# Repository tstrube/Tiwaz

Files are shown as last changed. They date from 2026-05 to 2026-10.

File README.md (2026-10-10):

# Tiwaz

Tiwaz is a split keyboard with gasket mounted plate and hot-swappable switches. Each half works standalone as a one-handed controller or macro pad. This makes this one of the only gaming keyboards for left handed users. 

The defining feature are the joysticks. They can operate as regular analog gamepad sticks, digital buttons, or mouse input, and use ribbon cables to connect to the PCB.

There are multiple options including solder pads that allow access to the joysticks pins for custom applications.

QMK and VIAL support allow button remapping in the browser without manual reflashing.

### TLDR Links:

- Detailed project presentation: [Hackaday](https://hackaday.io/project/206615-tiwaz-gaming-keyboard-macro-pad/details)
- Purchase here: [Crowd Supply](https://www.crowdsupply.com/ts-consulting/tiwaz)
- CAD files: [Printables](https://www.printables.com/model/1715647-tiwaz-split-gaming-keyboard-gasket-mounted), [Makerworld](https://makerworld.com/en/models/3280355-tiwaz-gaming-keyboard-macropad), [Thingiverse](https://www.thingiverse.com/thing:7404971)
- Custom keycaps: [Left half](https://custom.fkcaps.com/custom/ZMRFDB), [Right half](https://custom.fkcaps.com/custom/MJQDKY), [Both](https://custom.fkcaps.com/custom/L3QJ2N)
- Assembly video: [YouTube](https://www.youtube.com/watch?v=tHYdIYXT8AQ)
- Firmware: [QMK](https://github.com/tstrube/qmk_firmware/tree/tiwaz/keyboards/tiwaz), [VIAL](https://github.com/tstrube/vial-qmk/tree/tiwaz/keyboards/tiwaz)
- Subreddit: [Reddit](https://www.reddit.com/r/TiwazKeyboard/)
- Get in touch: [X](https://x.com/TimoStrube)

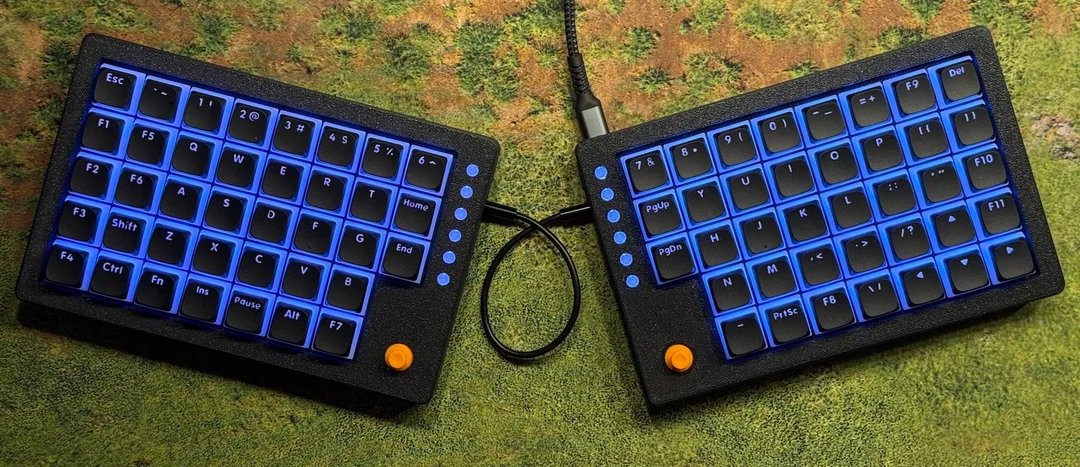
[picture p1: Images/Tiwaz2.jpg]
Tiwaz Split

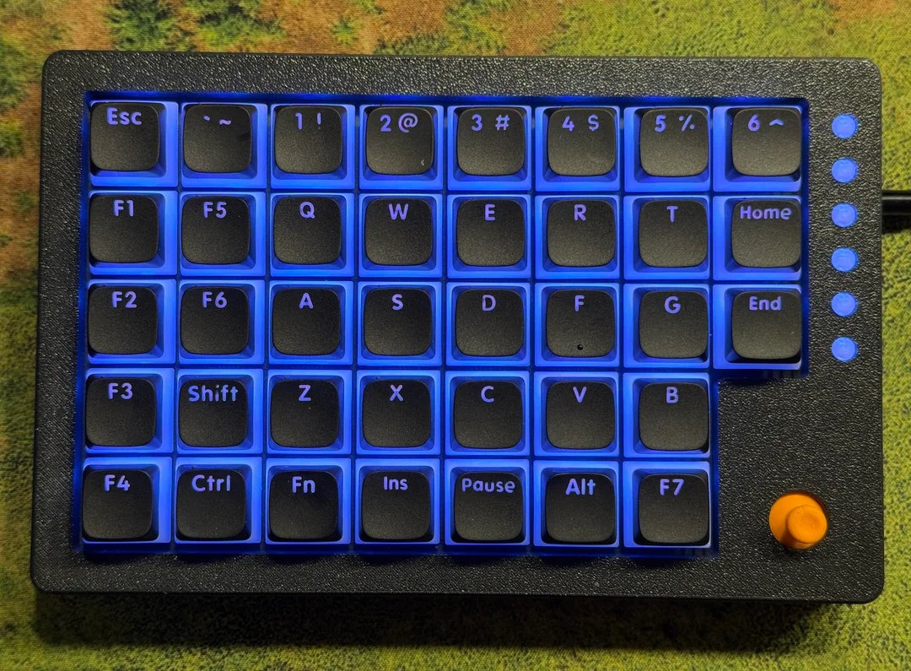
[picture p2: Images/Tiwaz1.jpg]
Detail

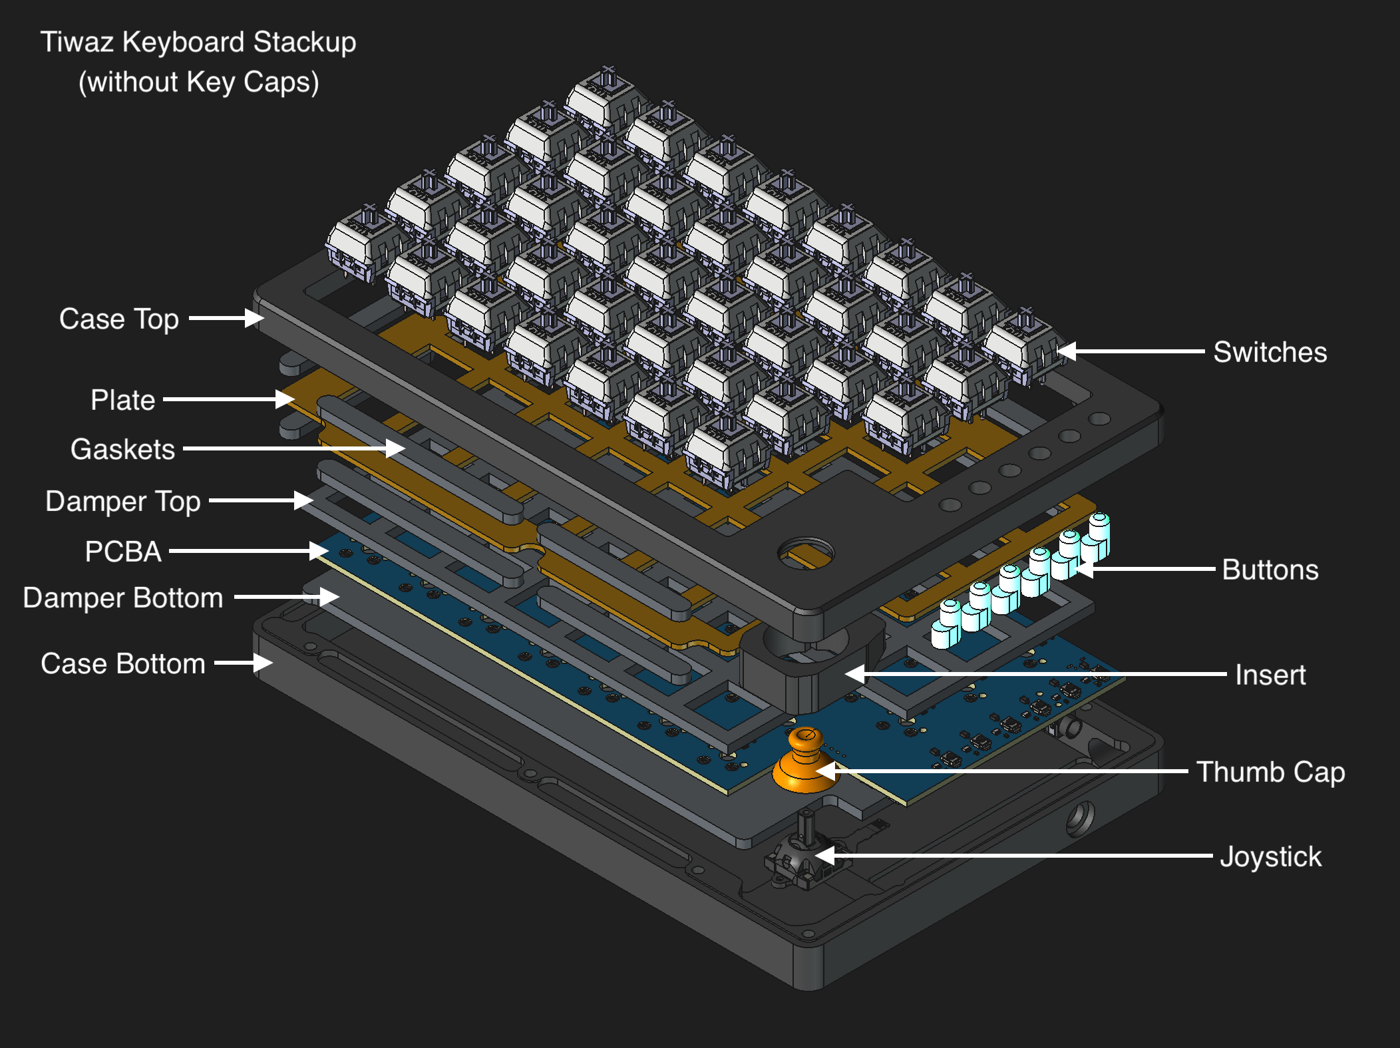
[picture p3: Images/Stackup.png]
Exploded view

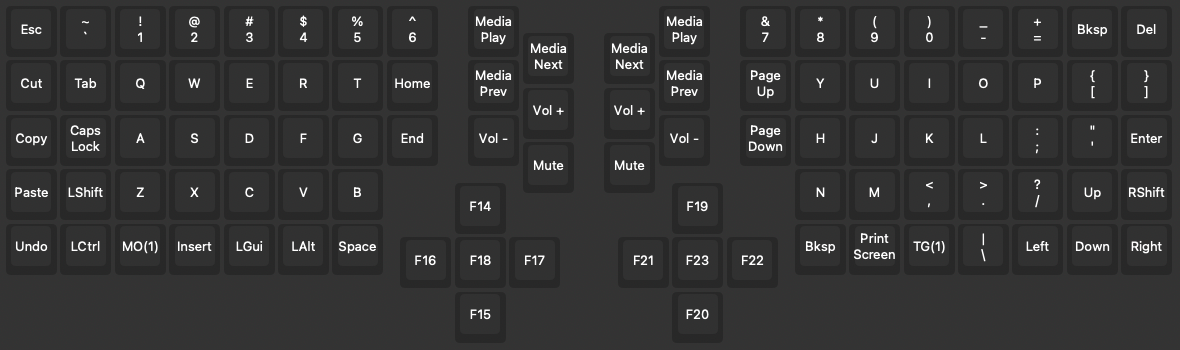
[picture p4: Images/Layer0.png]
Layer 0

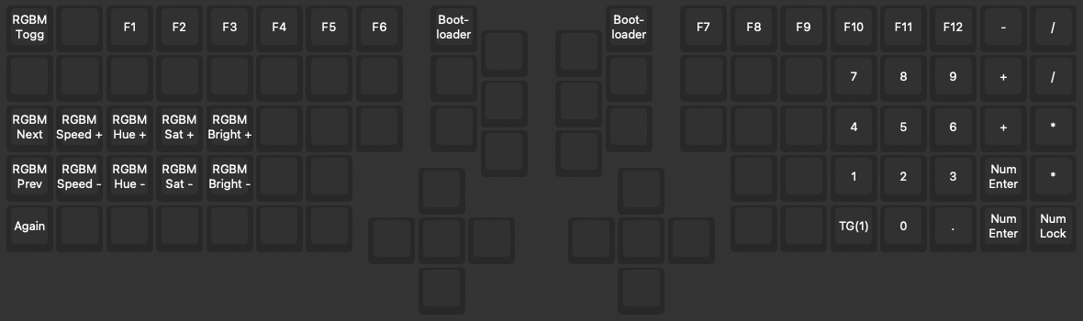
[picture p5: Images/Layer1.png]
Layer 1


[More Images](Images/README.md)

## Features

- Each half usable standalone as a one-handed controller or macro pad
- Two joystick options (Alps Alpine [RKJX21224001](https://tech.alpsalpine.com/e/products/detail/RKJX21224001/) / [PSP3000-style RKJXU1210006](https://tech.alpsalpine.com/e/products/detail/RKJXU1210006/))
- 6 separate media keys
- all switches and buttons are RGB backlit
- FN + lowest media key switch Joystick input mode (digital buttons (blue indicator light), analog gamepad (yellow), mouse (red))
  - digital buttons: 4 directions + center button, can be used as regular buttons or arrow keys, for example
  - analog gamepad: the joysticks are recognized as gamepad axes with a gamepad button
  - mouse: the joysticks control the mouse cursor, clicking by pressing the joystick down. To drag move before 500ms after pressing down, otherwise it will be a right click.
  - the indicator light is hardcoded. It is recommended to not change this key mapping
- Gasket mounted plate for a dampened typing feel
- Dapening material between Plate and PCB, as well as PCB and case
- [QMK firmware](https://github.com/tstrube/qmk_firmware/tree/tiwaz/keyboards/tiwaz) *([pull-request pending](https://github.com/qmk/qmk_firmware/pull/26438))* - [QMK website](https://www.qmk.fm/)
- [VIAL firmware](https://github.com/tstrube/vial-qmk/tree/tiwaz/keyboards/tiwaz) *(pull-request after QMK merged)* - [VIAL website](https://get.vial.today/)

## PCB details

- STM32F401RET6 MCU
- 38 hot-swap connectors for MX type switches
- 6 auxiliary buttons (intended as media keys, but remappable, of course)
- WS2812 RGB LED for each switch and button
- AUX connector for power and data transmission to the other half (only one half should be connected to the PC at any time)
- Ideal diode to protect against accidentally plugging in both halves while they are connect to each other
- Self-resetting fuse to to protect against high power draw of the LEDs (though limited in firmware)
- ESD protection on the USB and AUX connectors
- Solder points for joystick pins (ADC (2x), GPIO, GND, 3V3) 

## Bill of Materials

- PCB available on [Crowd Supply](https://www.crowdsupply.com/ts-consulting/tiwaz)
- Case available on [Printables](https://www.printables.com/model/1715647-tiwaz-split-gaming-keyboard-gasket-mounted), [Makerworld](https://makerworld.com/en/models/3280355-tiwaz-gaming-keyboard-macropad), [Thingiverse](https://www.thingiverse.com/thing:7404971)
- Ergo Keycaps (not affiliated, just recommendations. There are very few backlit 1u sets available)
  - FK custom: [Left half](https://custom.fkcaps.com/custom/ZMRFDB), [Right half](https://custom.fkcaps.com/custom/MJQDKY), [Both halves](https://custom.fkcaps.com/custom/L3QJ2N)
  - [LPF Glow Legended Low Profile MX Keycaps](https://splitkb.com/products/lpf-glow-legended-mx-keycaps)
  - [THT (Tai-Hao Thins) Low Profile Keycaps - 98 PCS](https://shop.tai-hao.com/products/98black)
  - [THT (Tai-Hao Thins) Low Profile Keycaps - 65 Keys](https://shop.tai-hao.com/products/black-low-profile-keycaps)
  - [THT (Tai-Hao Thins) Low Profile Keycaps - Blanks](https://shop.tai-hao.com/products/taihao-black-low-profile-keycap-1u-dot-pbt-backlit)

## Assembly video

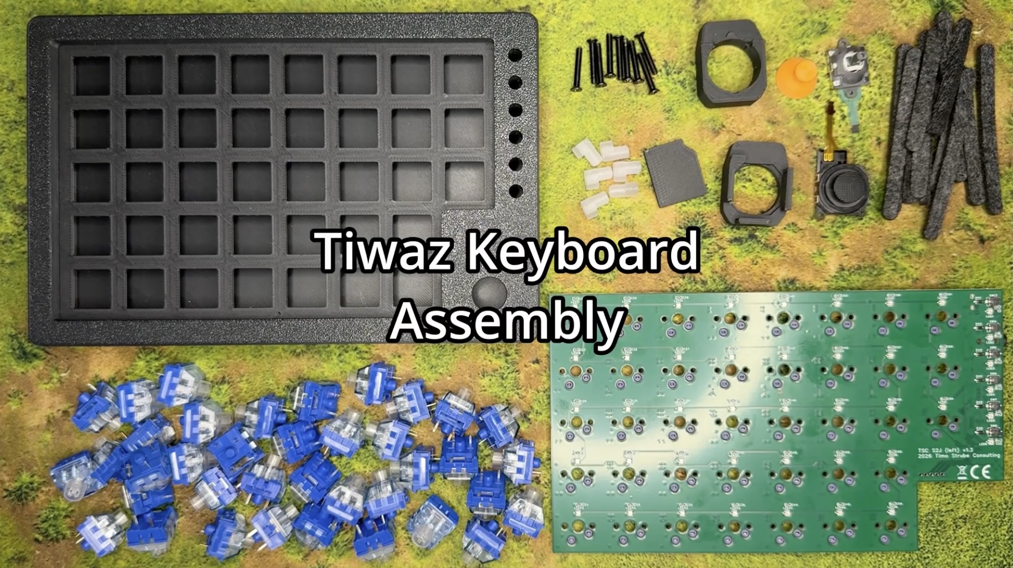
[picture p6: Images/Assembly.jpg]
Tiwaz Assembly (https://www.youtube.com/watch?v=tHYdIYXT8AQ)

[Watch the assembly video on YouTube](https://www.youtube.com/watch?v=tHYdIYXT8AQ)

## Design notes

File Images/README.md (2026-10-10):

Tiwaz Split
*Split keyboard*

---

Tiwaz Detail
*Left half detail view*

---

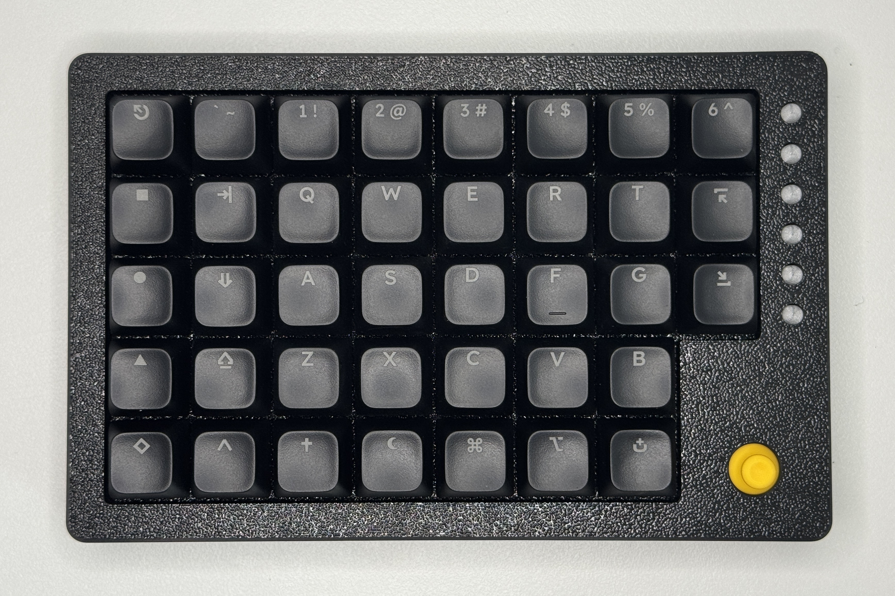
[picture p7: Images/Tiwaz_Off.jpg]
Tiwaz Off

*Backlight off*

---

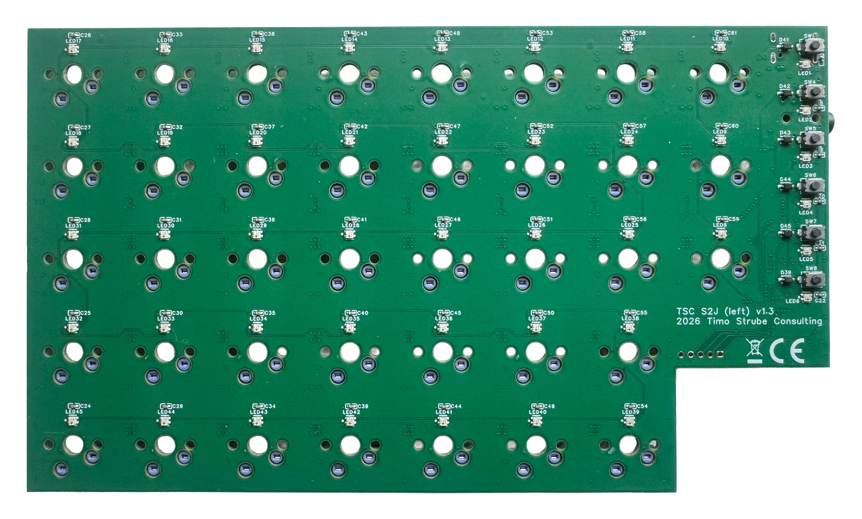
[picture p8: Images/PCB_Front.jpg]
Tiwaz PCB

*PCB front*

---

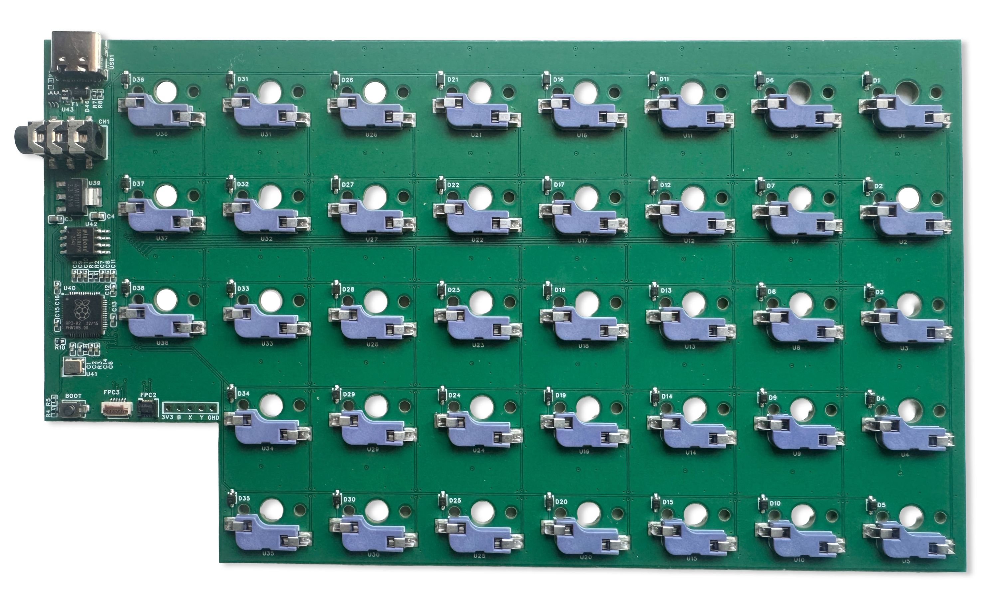
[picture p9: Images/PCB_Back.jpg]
Tiwaz PCB Back

*PCB back (old version with RP2040 instead of STM32F401)*

---

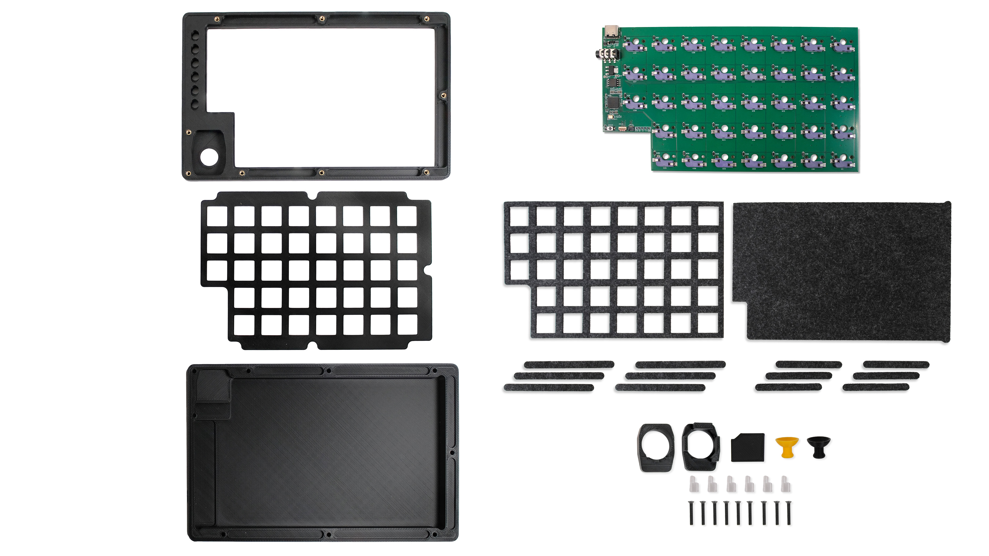
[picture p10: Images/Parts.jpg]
Tiwaz Parts

*All parts of one half of the keyboard*

---

Tiwaz Stackup
*Keyboard stackup*

---

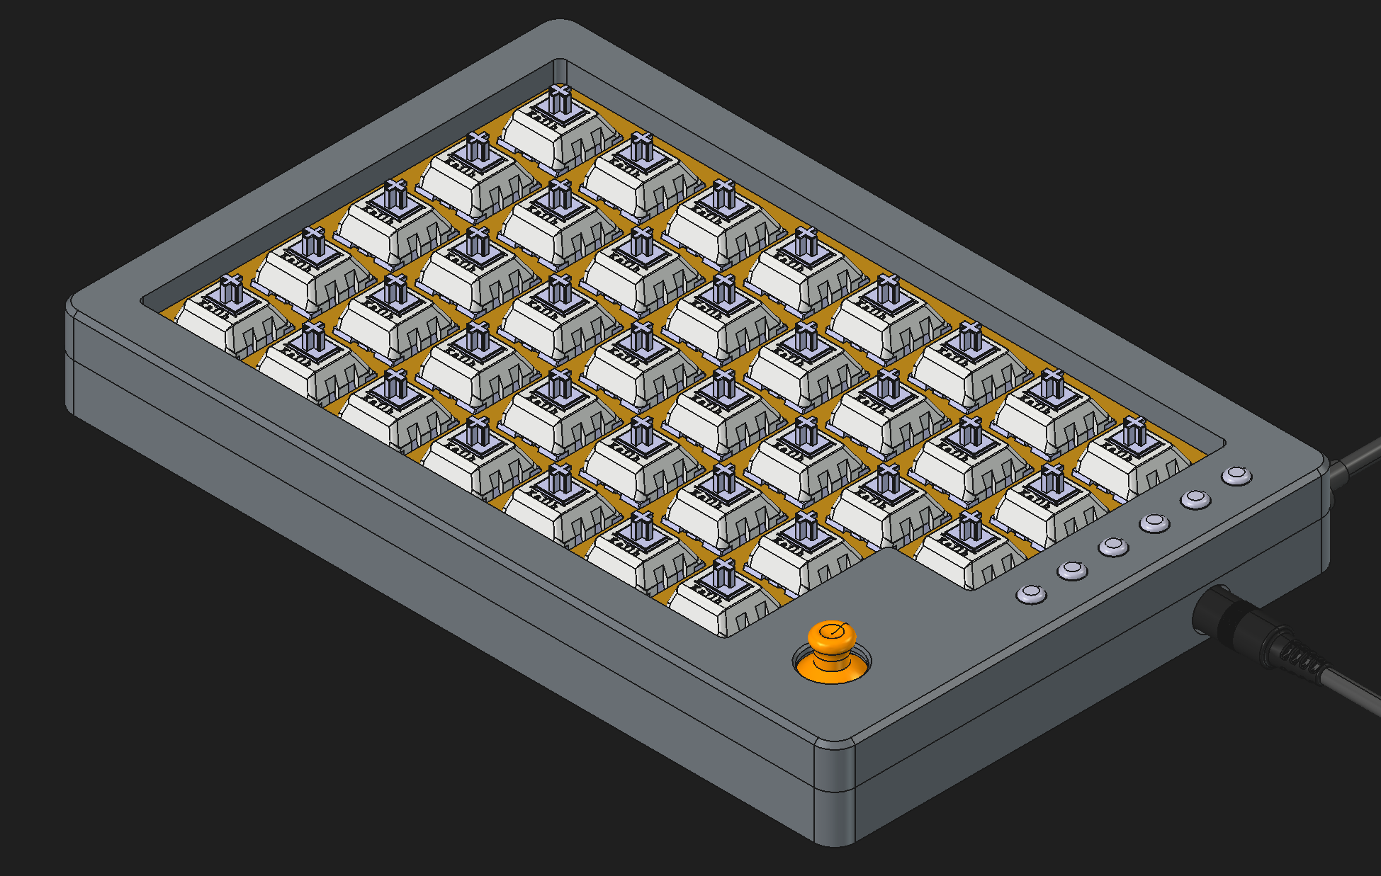
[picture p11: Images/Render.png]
Tiwaz Render

*3D Render*

---

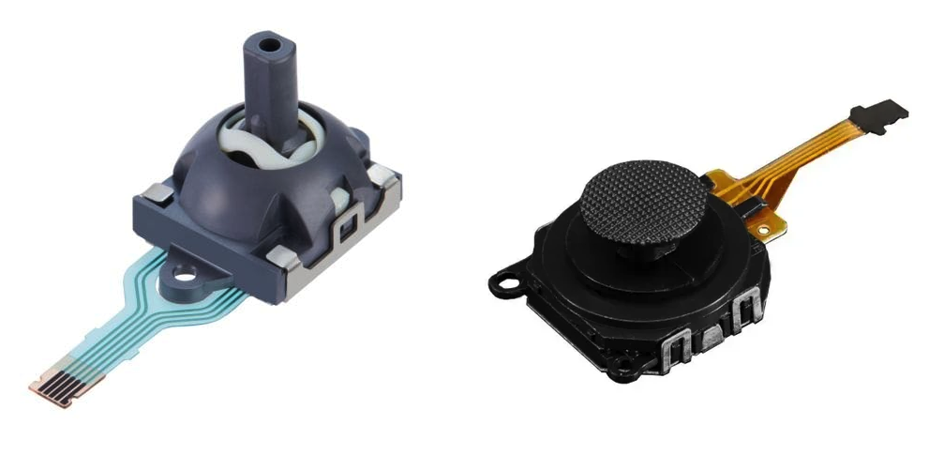
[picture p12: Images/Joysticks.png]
Joystick options

*Joystick options (left: RKJX21224001, right: RKJXU1210006 (PSP3000))*

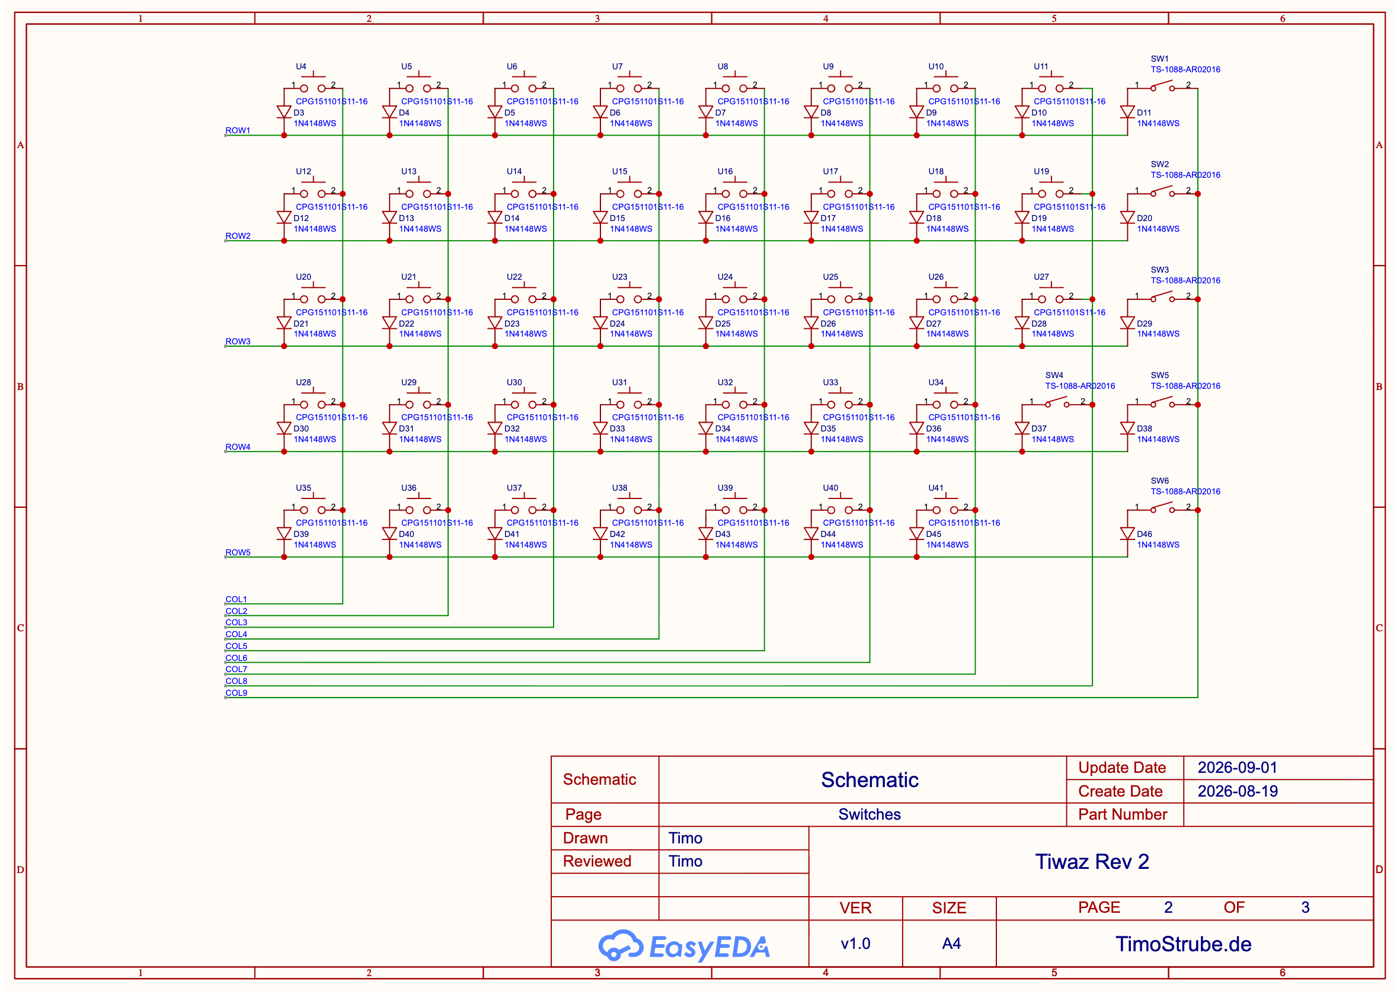
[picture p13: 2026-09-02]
PCB/Schematic/2_Switches.png

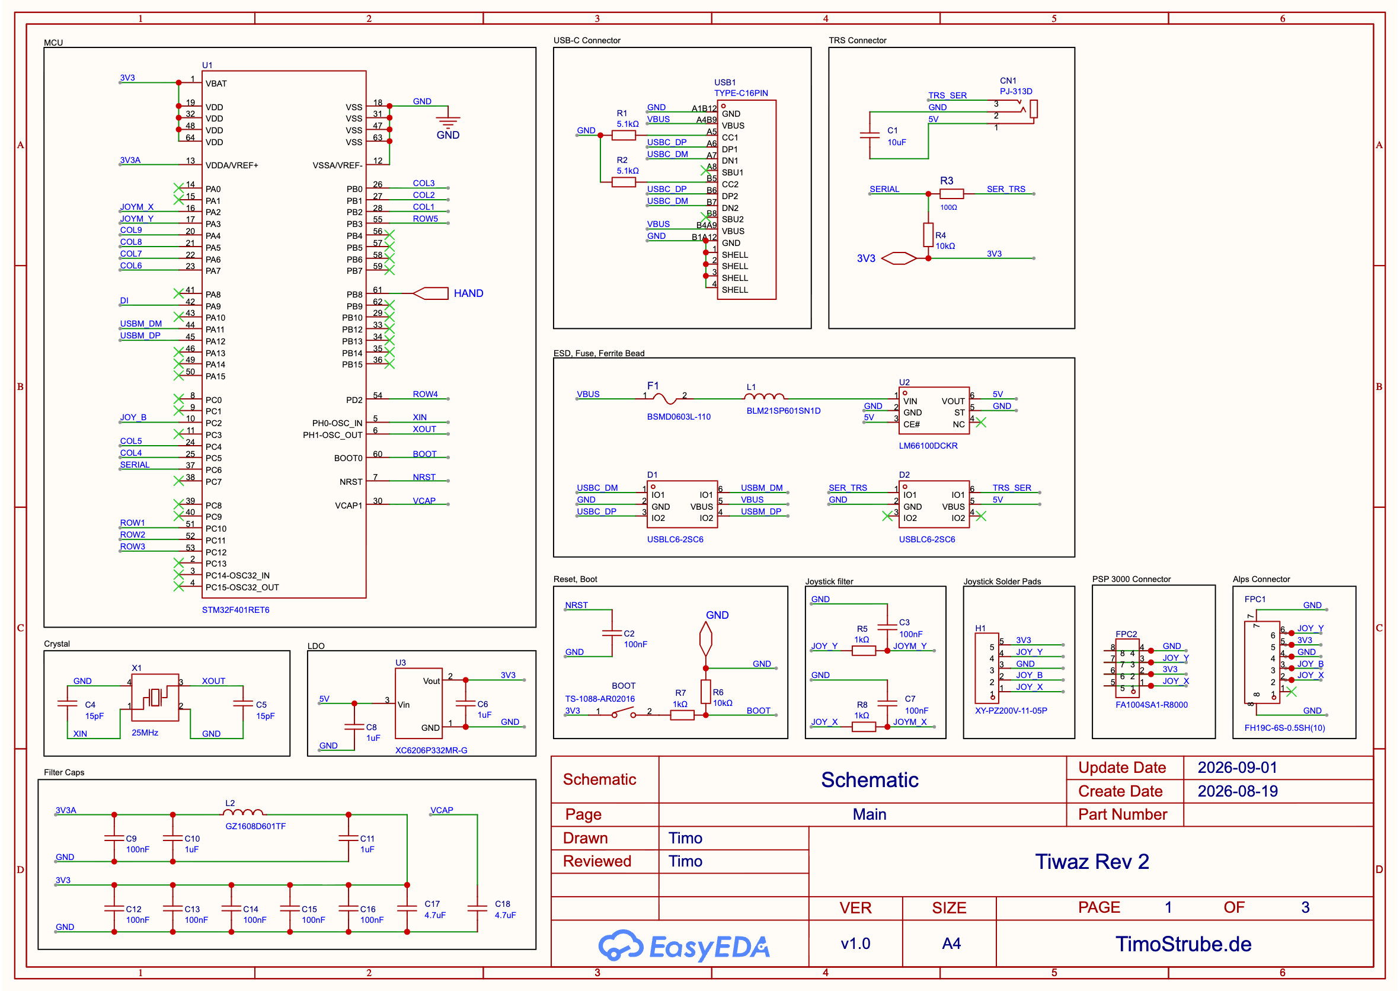
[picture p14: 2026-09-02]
PCB/Schematic/1_Main.png

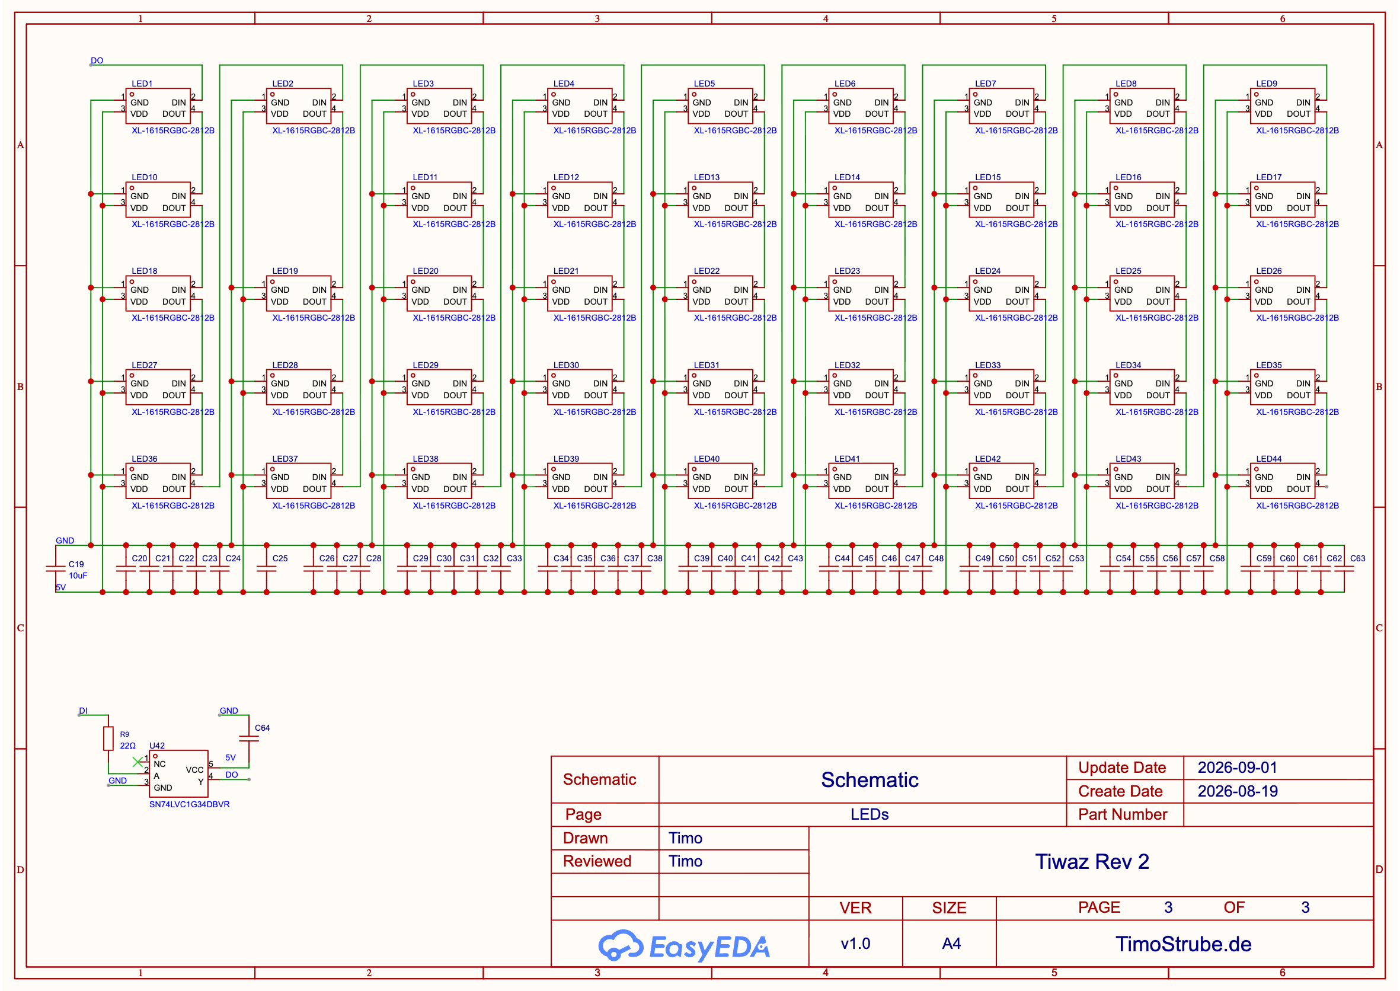
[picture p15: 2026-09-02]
PCB/Schematic/3_LEDs.png

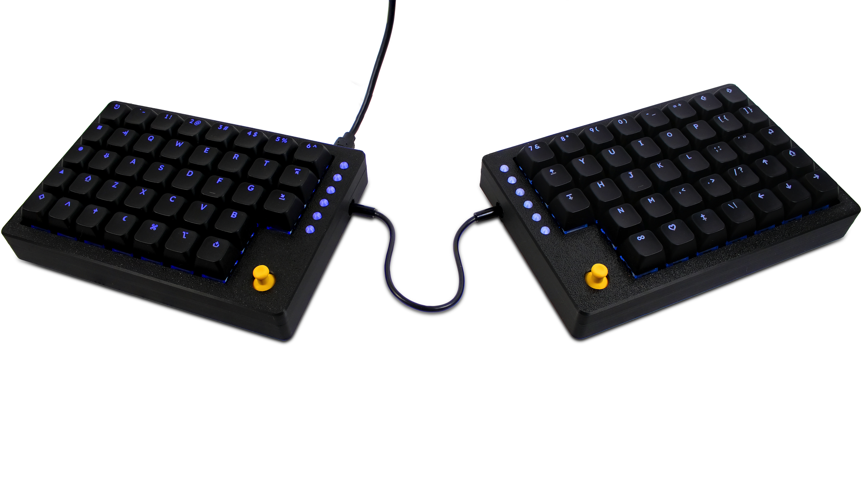
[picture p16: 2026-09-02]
Images/Tiwaz.jpg

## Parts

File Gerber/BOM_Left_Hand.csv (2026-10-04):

No. | Quantity | Designator | Name | Footprint | Manufacturer Part | Manufacturer | Supplier Part | Supplier
1 | 7 | BOOT,SW1,SW2,SW3,SW4,SW5,SW6 | TS-1088-AR02016 | SW-SMD_L3.9-W3.0-P4.45 | TS-1088-AR02016 | XUNPU(讯普) | C720477 | LCSC
2 | 2 | C1,C19 | 10uF | C0603 | CL10A106KP8NNNC | SAMSUNG(三星) | C19702 | LCSC
3 | 54 | C2,C3,C7,C9,C12,C13,C14,C15,C16,C20,C21,C22,C23,C24,C25,C26,C27,C28,C29,C30,C31,C32,C33,C34,C35,C36,C37,C38,C39,C40,C41,C42,C43,C44,C45,C46,C47,C48,C49,C50,C51,C52,C53,C54,C55,C56,C57,C58,C59,C60,C61,C62,C63,C64 | 100nF | C0402 | CL05B104KO5NNNC | SAMSUNG(三星) | C1525 | LCSC
4 | 2 | C4,C5 | 15pF | C0402 | 0402CG150J500NT | FH(风华) | C1548 | LCSC
5 | 4 | C6,C8,C10,C11 | 1uF | C0402 | CL05A105KA5NQNC | SAMSUNG(三星) | C52923 | LCSC
6 | 2 | C17,C18 | 4.7uF | C0603 | CL10A475KO8NNNC | SAMSUNG(三星) | C19666 | LCSC
7 | 1 | CN1 | PJ-313D | AUDIO-SMD_PJ-313D-2 | PJ-313D | SHOU HAN(首韩) | C668608 | LCSC
8 | 2 | D1,D2 | USBLC6-2SC6 | SOT-23-6_L2.9-W1.6-P0.95-LS2.8-BL | USBLC6-2SC6 | TECH PUBLIC(台舟) | C2827654 | LCSC
9 | 44 | D3,D4,D5,D6,D7,D8,D9,D10,D11,D12,D13,D14,D15,D16,D17,D18,D19,D20,D21,D22,D23,D24,D25,D26,D27,D28,D29,D30,D31,D32,D33,D34,D35,D36,D37,D38,D39,D40,D41,D42,D43,D44,D45,D46 | 1N4148WS | SOD-323_L1.8-W1.3-LS2.5-RD | 1N4148WS | CJ(江苏长电/长晶) | C2128 | LCSC
10 | 1 | F1 | BSMD0603L-110 | F0603 | BSMD0603L-110 | BHFUSE(佰宏) | C914093 | LCSC
11 | 1 | FPC1 | FH19C-6S-0.5SH(10) | FPC-SMD_FH19C-6S-0.5SH | FH19C-6S-0.5SH(10) | HRS(广濑) | C424651 | LCSC
12 | 1 | FPC2 | FA1004SA1-R8000 | CONN-SMD_FA1004SA1-R8000 | FA1004SA1-R8000 | JAE(日本航空电子) | C6853347 | LCSC
13 | 1 | H1 | XY-PZ200V-11-05P | HDR-TH_XY-PZ200V-11-05P | XY-PZ200V-11-05P | XYECONN(辛译) | C53200672 | LCSC
14 | 1 | L1 | BLM21SP601SN1D | L0805 | BLM21SP601SN1D | muRata(村田) | C3716677 | LCSC
15 | 1 | L2 | GZ1608D601TF | L0603 | GZ1608D601TF | Sunlord(顺络) | C1002 | LCSC
16 | 44 | LED1,LED2,LED3,LED4,LED5,LED6,LED7,LED8,LED9,LED10,LED11,LED12,LED13,LED14,LED15,LED16,LED17,LED18,LED19,LED20,LED21,LED22,LED23,LED24,LED25,LED26,LED27,LED28,LED29,LED30,LED31,LED32,LED33,LED34,LED35,LED36,LED37,LED38,LED39,LED40,LED41,LED42,LED43,LED44 | XL-1615RGBC-WS2812B | LED-SMD_4P-L1.6-W1.5_XL-1615RGBC-WS2812B-1 | XL-1615RGBC-WS2812B | XINGLIGHT(成兴光) | C5349954 | LCSC
17 | 2 | R1,R2 | 5.1kΩ | R0402 | 0402WGF5101TCE | UNI-ROYAL(厚声) | C25905 | LCSC
18 | 1 | R3 | 100Ω | R0402 | 0402WGF1000TCE | UNI-ROYAL(厚声) | C25076 | LCSC
19 | 3 | R4,R6,R10 | 10kΩ | R0402 | 0402WGF1002TCE | UNI-ROYAL(厚声) | C25744 | LCSC
20 | 3 | R5,R7,R8 | 1kΩ | R0402 | 0402WGF1001TCE | UNI-ROYAL(厚声) | C11702 | LCSC
21 | 1 | R9 | 22Ω | R0402 | 0402WGF220JTCE | UNI-ROYAL(厚声) | C25092 | LCSC
22 | 1 | U1 | STM32F401RET6 | LQFP-64_L10.0-W10.0-P0.50-LS12.0-BL | STM32F401RET6 | ST(意法半导体) | C116978 | LCSC
23 | 1 | U2 | LM66100DCKR | SC-70-6_L2.0-W1.3-P0.65-LS2.1-BL | LM66100DCKR | TI(德州仪器) | C2869734 | LCSC
24 | 1 | U3 | XC6206P332MR-G | SOT-23-3_L2.9-W1.6-P1.90-LS2.8-BR | XC6206P332MR-G | TOREX(特瑞仕) | C5446 | LCSC
25 | 38 | U4,U5,U6,U7,U8,U9,U10,U11,U12,U13,U14,U15,U16,U17,U18,U19,U20,U21,U22,U23,U24,U25,U26,U27,U28,U29,U30,U31,U32,U33,U34,U35,U36,U37,U38,U39,U40,U41 | CPG151101S11-16 | SMD_KEYBOARD-SW_COMPLETE | CPG151101S11-16 | HanElectricity(瀚源) | C41430893 | LCSC
26 | 1 | U42 | SN74LVC1G34DBVR | SOT-23-5_L2.9-W1.6-P0.95-LS2.8-BR | SN74LVC1G34DBVR | TI(德州仪器) | C840096 | LCSC
27 | 1 | USB1 | TYPE-C16PIN | USB-C-SMD_TYPE-C16PIN | TYPE-C16PIN | SHOU HAN(首韩) | C393939 | LCSC
28 | 1 | X1 | 25MHz | CRYSTAL-SMD_4P-L3.2-W2.5-BL | X322525MOB4SI | YXC(扬兴晶振) | C9006 | LCSC

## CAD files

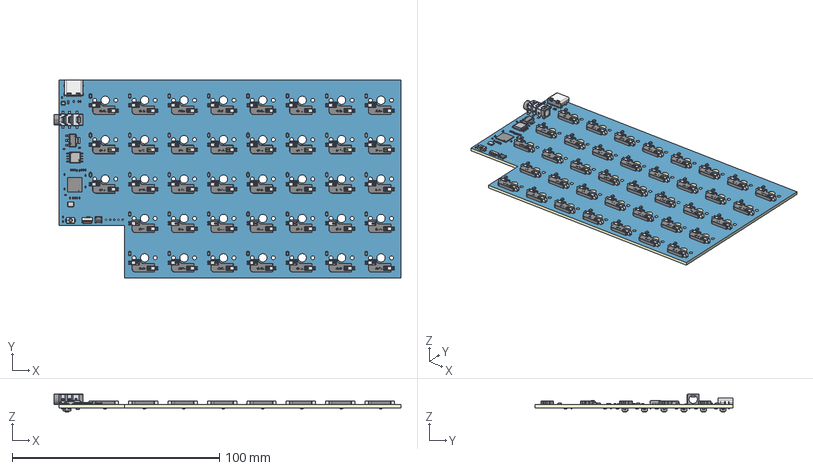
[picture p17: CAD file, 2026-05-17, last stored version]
PCB/Step.step
167.4 x 95.4 x 8.55 mm
Board~j4s0
TopCopper~j4s0
BottomCopper~j4s0
TopFpcStiffener~j4s0
BottomFpcStiffener~j4s0
R0402~R0402_L1.0-W0.5-H0.5~j4s0 x 9
SOT-223-3_L6.5-W3.4-P2.30-LS7.0-BR~SOT-223-3_ L6.5-W3.4-P2.30-LS7.0-L~j4s0
SOIC-8_L5.3-W5.3-P1.27-LS8.0-BL~SOIC-8_L5.3-W5.3-P1.27-LS8.2-BL~j4s0
CRYSTAL-SMD_4P-L3.2-W2.5-BL~CRYSTAL-SMD_4P-L3.2-W2.5-BL-2~j4s0
AUDIO-SMD_PJ-313D-2~AUDIO-SMD_PJ-313D-2~j4s0
C0402~C0402~j4s0 x 60
F0603~F0603_L1.7-W0.9-H0.7~j4s0
SC-70-6_L2.0-W1.3-P0.65-LS2.1-BL~SC-70-6_L2.0-W1.3-P0.65-LS2.1-BL~j4s0
USB-C-SMD_TYPE-C16PIN~USB-C-SMD_TYPE-C16PIN~j4s0
LQFN-56_L7.0-W7.0-P0.4-EP~QFN-56_L7.0-W7.0-P0.40-TL-EP4.6~j4s0
SW-SMD_L3.9-W3.0-P4.45~SW-SMD_L3.9-W2.9-H2.0-LS4.8~j4s0 x 7
LED-SMD_4P-L1.6-W1.5_XL-1615RGBC-WS2812B-1~LED-SMD_4P-L1.6-W1.5_ XL-1615RGBC-WS2812B~j4s0 x 44
SOD-323_L1.8-W1.3-LS2.5-RD~SOD-323_L1.8-W1.3-LS2.5-RD-1~j4s0 x 44
SMD_KEYBOARD-SW_COMPLETE~SW-SMD_KAILH-SOCKET_C9900019772~j4s0 x 38
CONN-SMD_FA1004SA1-R8000~CONN-SMD_FA1004SA1-R8000~j4s0
FPC-SMD_FH19C-6S-0.5SH~FPC-SMD_FH19C-6S-0.5SH~j4s0
SOT-23-3_L3.0-W1.7-P0.95-LS2.9-BR~SOT-23-3L_ L2.9-W1.6-H1.1-LS2.8-P0.95~j4s0

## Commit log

2026-05-27 fixed QSPI. added compiled firmware
    [BOM.csv]
2026-05-29 added assembly video and more information about joystick modes
2026-09-02 crowd supply release version
    [BOM.csv, Step.step]
2026-09-02 added images of PCB
2026-10-04 added gerber, bom, pickplace files
    [BOM_Left_Hand.csv, BOM_Right_Hand.csv, PickAndPlace_Left_Hand.csv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]
